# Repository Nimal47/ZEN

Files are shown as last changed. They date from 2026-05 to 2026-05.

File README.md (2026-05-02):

# ZEN — Ambient Desk Intelligent System (ADIS)

> An IoT-based smart desk system that monitors student productivity through real-time presence detection and device usage tracking.

---

## What It Does

ZEN sits on your desk and silently tracks how focused you actually are:

- **Presence Detection** — A PIR sensor continuously checks if you're at your desk
- **Phone Distraction Tracking** — An RFID tag on your phone logs every time you pick it up, giving you a distraction count and duration
- **On-Desk Interface** — A TFT display with button navigation gives you a timer, stopwatch, and reminder alerts without needing your phone
- **Productivity Analytics** — All sensor data is logged to Firebase and visualized in a companion app (in progress)

---

## Hardware Components

| Component | Model |
|---|---|
| Microcontroller | ESP32 DOIT DevKit V1 |
| Display | TFT ST7735 / ST7789 |
| OLED | SSD1306 128×64 |
| RFID Module | MFRC522 |
| Presence Sensor | PIR Motion Sensor |
| Power | LiPo Battery |
| Buttons | 2× Tactile Push Buttons |

---

## Pin Configuration

### TFT Display (SPI)
| TFT Pin | ESP32 GPIO |
|---|---|
| CS | 5 |
| DC | 2 |
| RST | 4 |
| SCK | 18 (VSPI default) |
| MOSI | 23 (VSPI default) |

### RFID — MFRC522 (SPI, shared bus)
| RFID Pin | ESP32 GPIO |
|---|---|
| CS (SDA) | 21 |
| RST | 22 |
| SCK | 18 |
| MOSI | 23 |
| MISO | 19 |

### OLED — SSD1306 (I2C)
| OLED Pin | ESP32 GPIO |
|---|---|
| SDA | 25 |
| SCL | 26 |

### Other
| Component | ESP32 GPIO |
|---|---|
| PIR Sensor OUT | 27 |
| Button — Mode | 32 |
| Button — Timer | 33 |
| PIR VCC | VIN |
| Battery + | VIN |

---

## Project Structure

```
ZEN/
├── src/                  # Main firmware source code
├── include/              # Header files
├── lib/                  # Local libraries
├── test/                 # PlatformIO unit tests (simulated/virtual)
├── hardware_tests/       # Real-world hardware validation scripts
├── 3D_MODEL/             # 3D printable enclosure files
├── platformio.ini        # PlatformIO build config
└── secret.example.h      # Template for WiFi & Firebase credentials
```

> **`test/` vs `hardware_tests/`** — `test/` is for PlatformIO's native unit testing framework (edge case simulation). `hardware_tests/` contains scripts used to verify real hardware behavior during development.

---

## Getting Started

### 1. Prerequisites

- [PlatformIO](https://platformio.org/) (VS Code extension or CLI)
- ESP32 board drivers installed
- A Firebase project with Realtime Database enabled

### 2. Clone the Repo

```bash
git clone https://github.com/Nimal47/ZEN.git
cd ZEN
```

### 3. Set Up Credentials

Copy the example secrets file and fill in your own values:

```bash
cp secret.example.h include/secret.h
```

Then open `include/secret.h` and fill in your WiFi and Firebase details. **Never commit `secret.h`** — it's already in `.gitignore`.

### 4. Flash to ESP32

```bash
pio run --target upload
```

Monitor serial output:

```bash
pio device monitor
```

---

## Firebase Setup

1. Go to [Firebase Console](https://console.firebase.google.com/) and create a new project
2. Enable **Realtime Database** (start in test mode for development)
3. Go to **Project Settings → Service Accounts** and note your database URL
4. Go to **Project Settings → General** and copy your **Web API Key**
5. Fill these into `include/secret.h`

---

## Dependencies (auto-installed by PlatformIO)

| Library | Purpose |
|---|---|
| Adafruit GFX Library | Graphics primitives |
| Adafruit ST7735/ST7789 | TFT display driver |
| Adafruit SSD1306 | OLED display driver |
| MFRC522 | RFID module |
| ArduinoJson | JSON serialization |
| Firebase Arduino Client Library | Firebase Realtime Database |

---

## Companion App

A mobile companion app that visualizes your productivity data from Firebase is currently in development. It will show daily distraction counts, focus session durations, and trend graphs.

---

## License

This project is licensed under the [MIT License](LICENSE).

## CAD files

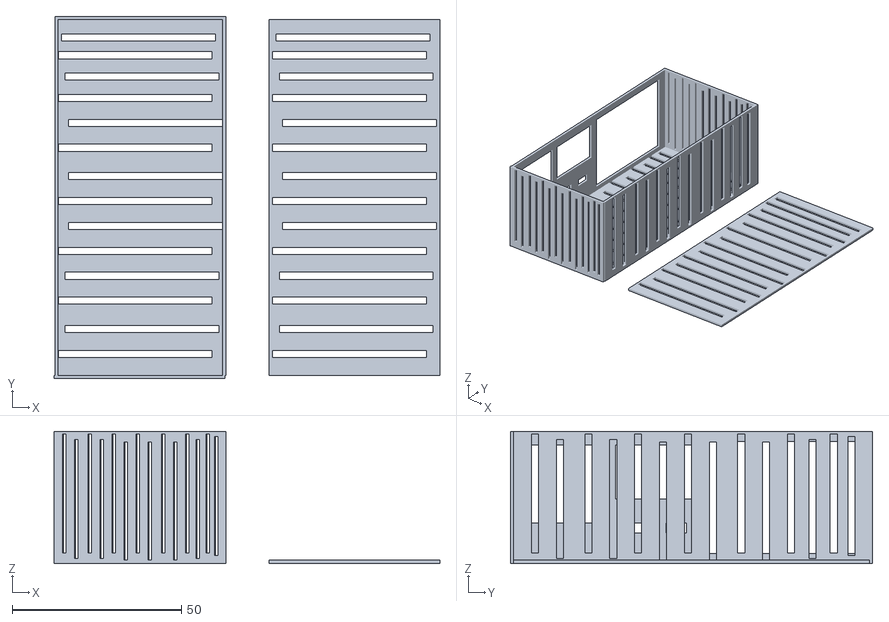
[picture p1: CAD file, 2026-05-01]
3D_MODEL/Final_model.stl
114.0 x 107.0 x 39.0

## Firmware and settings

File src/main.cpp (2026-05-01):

#include <Arduino.h>
#include <SPI.h>
#include <Adafruit_GFX.h>
#include <Adafruit_ST7735.h>
#include <MFRC522.h>
#include <WiFi.h>
#include "time.h"
#include <Adafruit_SSD1306.h>
#include <Firebase_ESP_Client.h>
#include <ArduinoJson.h>
#include "addons/RTDBHelper.h"
#include "/Users/nimal/Documents/PROJEC/MP3/django.h" //path to Image Header File in C array Format
#include "/Users/nimal/Documents/PROJEC/ADIS/src/secret.h" //path to your Credential folder 

// --- WI-FI CREDENTIALS ---
const char* ssid     = WIFI_SSID;
const char* password = WIFI_PASSWORD;

// --- SYSTEM TIMING CONSTANTS ---
#define SCREEN_AWAKE_MS       10000  
#define SCREEN_SLEEP_WARN_MS  12000  
#define TIMER_AUTOSTART_SEC   5      
#define TIME_UP_DISPLAY_MS    5000   
#define RFID_TIMEOUT_MS       2000   
#define FOCUS_POPUP_MS        3000   
#define SYNC_HOUR             23
#define SYNC_MINUTE           30

// --- PIN DEFINITIONS ---
#define TFT_CS      5
#define TFT_DC      2
#define TFT_RST     4
#define PIR_PIN     27
#define RFID_CS     21
#define RFID_RST    22
#define BTN_MODE    32 
#define BTN_TIMER   33 

#define OLED_SDA    25
#define OLED_SCL    26
#define SCREEN_WIDTH 128
#define SCREEN_HEIGHT 64

// --- HARDWARE OBJECTS ---
Adafruit_ST7735 tft = Adafruit_ST7735(TFT_CS, TFT_DC, TFT_RST);
MFRC522 mfrc522(RFID_CS, RFID_RST);
Adafruit_SSD1306 oled(SCREEN_WIDTH, SCREEN_HEIGHT, &Wire, -1);
FirebaseData fbdo;
FirebaseAuth auth;
FirebaseConfig config;

// --- SHARED RTOS VARIABLES & LOCKS ---
volatile TickType_t lastMotionTick = 0; 
SemaphoreHandle_t spiMutex;

// System Modes (NOW INCLUDES STOPWATCH)

enum SystemMode { MODE_DEFAULT, MODE_TIMER, MODE_STOPWATCH, MODE_REMINDER };
volatile SystemMode currentMode = MODE_DEFAULT;

// --- MANUAL TIMER VARIABLES ---
volatile int timerMinutes = 1;  
volatile TickType_t lastTimerInteractionTick = 0; 
volatile bool isTimerRunning = false;             
volatile TickType_t timerStartTick = 0;           
volatile TickType_t timeUpStartTick = 0; 

// Focus Session Data
struct FocusSession {
    String startTime;
    String endTime;
    int durationSec;
};

std::vector<FocusSession> dailyLog;
struct Reminder {
    String time;
    String text;
};
std::vector<Reminder> reminderList; // Holds all our downloaded reminders!

// --- NEW: STOPWATCH VARIABLES ---
volatile bool isStopwatchRunning = false;
volatile unsigned long accumulatedStopwatchSeconds = 0;
volatile TickType_t stopwatchStartTick = 0;

// --- PHONE JAIL NOTIFICATION VARIABLES ---
volatile bool isPhoneInJail = false;
volatile TickType_t jailStartTime = 0;
volatile bool showJailStartMessage = false;
volatile TickType_t jailStartMessageTick = 0;
volatile bool showJailSummary = false;
volatile TickType_t summaryStartTick = 0;
volatile int lastFocusSeconds = 0;

// Display States
enum DisplayState {
  STATE_AWAKE_DEFAULT,
  STATE_AWAKE_TIMER,
  STATE_AWAKE_STOPWATCH,   // NEW STATE!
  STATE_AWAKE_REMINDER,
  STATE_AWAKE_FOCUS_START, 
  STATE_AWAKE_SUMMARY,     
  STATE_SLEEPING_TEXT,
  STATE_ASLEEP
};

// =======================================================
// TASK 1: NETWORK MANAGER
// =======================================================
void networkTask(void *parameter) {
    Serial.println("📡 [NETWORK] Task started. Attempting Wi-Fi connection...");
    WiFi.begin(ssid, password);
    while (WiFi.status() != WL_CONNECTED) {
        vTaskDelay(pdMS_TO_TICKS(500));
        Serial.print(".");
    }
    Serial.println("\n✅ [NETWORK] Wi-Fi Connected!");
    Serial.print("🌐 [NETWORK] IP Address Assigned: ");
    Serial.println(WiFi.localIP());
    
    Serial.println("🕒 [NETWORK] Requesting NTP Time Sync...");
    configTime(19800, 0, "time.google.com");
    struct tm timeinfo;
    if (getLocalTime(&timeinfo)) {
        Serial.println("✅ [NETWORK] Time Synced Successfully!");
    } else {
        Serial.println("❌ [NETWORK] WARNING: Failed to obtain local time!");
    }
    
    Serial.println("🔥 [FIREBASE] Initializing connection to database...");
    config.database_url = FIREBASE_HOST;
    config.signer.tokens.legacy_token = FIREBASE_AUTH;
    Firebase.begin(&config, &auth);
    Firebase.reconnectWiFi(true);
    Serial.println("✅ [FIREBASE] Client Initialized.");

    bool hasSyncedToday = false;
    int lastPullMinute = -1; // Prevents fetching data multiple times in the same minute

    for (;;) {
        if (getLocalTime(&timeinfo)) {
            
            // 1. DAILY DATA PUSH (11:30 PM)
            if (timeinfo.tm_hour == SYNC_HOUR && timeinfo.tm_min == SYNC_MINUTE && !hasSyncedToday) {
                Serial.printf("\n☁️ [FIREBASE] --- INITIATING DAILY SYNC --- \n");
                Serial.printf("📊 [FIREBASE] Sessions currently in local buffer: %d\n", dailyLog.size());
                
                if (dailyLog.size() > 0) {
                    for (const auto& session : dailyLog) {
                        FirebaseJson json;
                        json.add("start", session.startTime);
                        json.add("end", session.endTime);
                        json.add("duration", session.durationSec);
                        
                        // Convert JSON to string just so we can print and verify it
                        String jsonStr;
                        json.toString(jsonStr, false);
                        Serial.printf("📤 [FIREBASE] Pushing Payload: %s\n", jsonStr.c_str());

                        // Attempt the actual push
                        if (Firebase.RTDB.pushJSON(&fbdo, "/focus_sessions", &json)) {
                            Serial.println("✅ [FIREBASE] Push Success! Saved at path: " + fbdo.dataPath());
                        } else {
                            Serial.println("❌ [FIREBASE] PUSH FAILED! Reason: " + fbdo.errorReason());
                        }
                    }
                    dailyLog.clear(); 
                    Serial.println("🗑️ [LOCAL LOG] Local buffer cleared for the next day.");
                } else {
                    Serial.println("ℹ️ [FIREBASE] No valid focus sessions to push today.");
                }
                Serial.println("☁️ [FIREBASE] --- DAILY SYNC COMPLETE --- \n");
                hasSyncedToday = true;
            }
            
            // Reset the sync flag at midnight
            if (timeinfo.tm_hour == 0) hasSyncedToday = false; 

            // 2. PERIODIC REMINDER PULL (Exactly once every 1 minutes)
            if (timeinfo.tm_min %  1 == 0 && timeinfo.tm_min != lastPullMinute) {
                lastPullMinute = timeinfo.tm_min; 
                
                Serial.println("\n📥 [FIREBASE] Requesting JSON reminders...");
                
                // Fetch the whole JSON object instead of a single string
                if (Firebase.RTDB.getJSON(&fbdo, "/reminders")) {
                    FirebaseJson &json = fbdo.jsonObject();
                    size_t len = json.iteratorBegin();
                    String key, value;
                    int type;
                    
                    reminderList.clear(); // Empty the old list from memory
                    
                    // Loop through the JSON and pull out every time and task
                    for (size_t i = 0; i < len; i++) {
                        json.iteratorGet(i, type, key, value);
                        value.replace("\"", ""); // Clean up JSON quote marks
                        reminderList.push_back({key, value});
                    }
                    json.iteratorEnd();
                    
                    Serial.printf("✅ [FIREBASE] Loaded %d reminders from cloud.\n", reminderList.size());
                } else {
                    Serial.println("❌ [FIREBASE] Failed to fetch reminders! Reason: " + fbdo.errorReason());
                }
            }
        }
        
        // Loop runs once a second to keep exact track of time without spamming
        vTaskDelay(pdMS_TO_TICKS(1000)); 
    }
}

// =======================================================
// TASK 2: PIR WATCHER
// =======================================================
void pirTask(void *parameter) {
  pinMode(PIR_PIN, INPUT);
  for (;;) {
    if (digitalRead(PIR_PIN) == HIGH) {
      lastMotionTick = xTaskGetTickCount(); 
    }
    vTaskDelay(pdMS_TO_TICKS(100)); 
  }
}

// --- UTILITY: GET TIME STRING ---
String getTimestamp() {
    struct tm timeinfo;
    if(!getLocalTime(&timeinfo)) return "00:00:00";
    char timeStr[20];
    strftime(timeStr, sizeof(timeStr), "%H:%M:%S", &timeinfo);
    return String(timeStr);
}

// =======================================================
// TASK 3: BUTTON MANAGER
// =======================================================
void buttonTask(void *parameter) {
  pinMode(BTN_MODE, INPUT_PULLUP);
  pinMode(BTN_TIMER, INPUT_PULLUP);

  int lastModeState = HIGH;
  int lastTimerState = HIGH;

  for (;;) {
    int modeState = digitalRead(BTN_MODE);
    int timerState = digitalRead(BTN_TIMER);

    // --- BUTTON 1: CHANGE MODE ---
    if (modeState == LOW && lastModeState == HIGH) {
      // Now cycles through 4 modes instead of 3
      currentMode = (SystemMode)((currentMode + 1) % 4); 
      lastMotionTick = xTaskGetTickCount(); 
      
      // Reset Timer if entering Timer Mode
      if (currentMode == MODE_TIMER) {
        lastTimerInteractionTick = xTaskGetTickCount();
        isTimerRunning = false; 
      }
      
      // Reset Stopwatch if entering Stopwatch Mode
      if (currentMode == MODE_STOPWATCH) {
        isStopwatchRunning = false;
        accumulatedStopwatchSeconds = 0; 
      }
      
      Serial.printf("🔘 Mode Switched: %d\n", currentMode);
    }
    lastModeState = modeState;

    // --- BUTTON 2: ACTION BUTTON ---
    if (timerState == LOW && lastTimerState == HIGH) {
      lastMotionTick = xTaskGetTickCount(); 
      
      // Action for Timer Mode
      if (currentMode == MODE_TIMER) {
        if (timerMinutes == 1) timerMinutes = 5;
        else if (timerMinutes == 5) timerMinutes = 15;
        else if (timerMinutes == 15) timerMinutes = 30;
        else if (timerMinutes == 30) timerMinutes = 60;
        else timerMinutes = 1; 
        
        lastTimerInteractionTick = xTaskGetTickCount(); 
        isTimerRunning = false;                         
        Serial.printf("⏱️ Timer Set To: %d min\n", timerMinutes);
      }
      
      // Action for Stopwatch Mode (Play/Pause Toggle)
      else if (currentMode == MODE_STOPWATCH) {
        if (isStopwatchRunning) {
          // PAUSE IT
          isStopwatchRunning = false;
          // Save the time we accrued so far
          accumulatedStopwatchSeconds += (xTaskGetTickCount() - stopwatchStartTick) / 1000;
          Serial.println("⏸️ Stopwatch Paused");
        } else {
          // START/RESUME IT
          isStopwatchRunning = true;
          stopwatchStartTick = xTaskGetTickCount();
          Serial.println("▶️ Stopwatch Started");
        }
      }
    }
    lastTimerState = timerState;
    vTaskDelay(pdMS_TO_TICKS(50)); 
  }
}

// =======================================================
// TASK 4: PHONE JAIL RFID
// =======================================================
void rfidTask(void *parameter) {
  // Give the main setup a moment to initialize the SPI bus
  vTaskDelay(pdMS_TO_TICKS(1000));
  
  if (xSemaphoreTake(spiMutex, portMAX_DELAY)) {
    mfrc522.PCD_Init();
    xSemaphoreGive(spiMutex);
  }
  
  TickType_t lastCardSeenTime = 0;
  String sessionStartStr; // Temporarily holds the start time for Firebase

  for (;;) {
    TickType_t currentTick = xTaskGetTickCount();
    MFRC522::StatusCode status;
    byte bufferATQA[2];
    byte bufferSize = sizeof(bufferATQA);

    // --- CRITICAL SECTION: LOCK SPI BUS TO READ RFID ---
    if (xSemaphoreTake(spiMutex, portMAX_DELAY)) {
      status = mfrc522.PICC_WakeupA(bufferATQA, &bufferSize);
      if (status == MFRC522::STATUS_OK && mfrc522.PICC_ReadCardSerial()) {
        mfrc522.PICC_HaltA(); 
      }
      xSemaphoreGive(spiMutex);
    }

    if (status == MFRC522::STATUS_OK) {
      lastCardSeenTime = currentTick;
      
      if (!isPhoneInJail) {
        // --- PHONE JUST ENTERED JAIL ---
        isPhoneInJail = true;
        jailStartTime = currentTick;
        sessionStartStr = getTimestamp(); // Capture the exact Start Time for Firebase
        
        showJailStartMessage = true;          // Trigger the 3-second Start Popup
        jailStartMessageTick = currentTick;   
        showJailSummary = false;              // Cancel any old summaries
        
        lastMotionTick = currentTick;         // Wake up screen instantly
        Serial.println("\n🔒 Phone Locked in Jail! Focus time started.");
      }
    } else {
      // Timeout Check: Phone lifted for more than 2 seconds (RFID_TIMEOUT_MS)
      if (isPhoneInJail && (currentTick - lastCardSeenTime > pdMS_TO_TICKS(RFID_TIMEOUT_MS))) {
        
        // --- PHONE JUST LEFT JAIL ---
        isPhoneInJail = false;
        
        // Calculate duration (subtracting the 2 second timeout buffer)
        int duration = (currentTick - jailStartTime - pdMS_TO_TICKS(RFID_TIMEOUT_MS)) / 1000;
        lastFocusSeconds = duration; // Save for the Display summary
        
        // --- FIREBASE LOGIC: ONLY SAVE IF > 15 MIN (900 seconds) ---
        Serial.printf("\n📱 [RFID] Phone removed. Total focus duration: %d seconds.\n", duration);
        if (duration >= 900) {
            dailyLog.push_back({sessionStartStr, getTimestamp(), duration});
            Serial.println("💾 Session valid (>15m). Saved to local buffer for 11:30 PM sync.");
        } else {
            Serial.println("⚠️ Session too short (<15m), discarded from Firebase log.");
        }
        
        showJailStartMessage = false;         // Cancel start message if picked up instantly
        showJailSummary = true;               // Trigger the 3-second End Popup
        summaryStartTick = currentTick;       
        
        lastMotionTick = currentTick;         // Wake up screen to show summary
        Serial.printf("🔓 Phone Removed! Focused for %d seconds\n", lastFocusSeconds);
      }
    }
    
    // Check for the phone twice a second
    vTaskDelay(pdMS_TO_TICKS(500)); 
  }
}

// =======================================================
// TASK 5: DISPLAY MANAGER
// =======================================================
void displayTask(void *parameter) {
  vTaskDelay(pdMS_TO_TICKS(500));
  
  if (xSemaphoreTake(spiMutex, portMAX_DELAY)) {
    tft.initR(INITR_BLACKTAB);
    tft.setRotation(1);
    tft.fillScreen(ST77XX_BLACK);
    xSemaphoreGive(spiMutex);
  }

  DisplayState currentState = STATE_ASLEEP; 
  int lastDrawnTimerSecond = -1; 
  int lastDrawnStopwatchSecond = -1; // Added for Stopwatch anti-flicker
  int lastSetupCountdown = -1; 

  for (;;) {
    TickType_t currentTick = xTaskGetTickCount();
    TickType_t timeSinceMotion = currentTick - lastMotionTick;

    // RULE 1: AWAKE
    if (timeSinceMotion < pdMS_TO_TICKS(SCREEN_AWAKE_MS)) {
      
      // --- NOTIFICATION OVERRIDE A: FOCUS STARTED ---
      if (showJailStartMessage) {
        lastMotionTick = currentTick; 
        if (currentState != STATE_AWAKE_FOCUS_START) {
          if (xSemaphoreTake(spiMutex, portMAX_DELAY)) {
            tft.fillScreen(ST77XX_BLACK);
            tft.setCursor(5, 50);
            tft.setTextColor(ST77XX_MAGENTA);
            tft.setTextSize(2);
            tft.print("FOCUS MODE");
            tft.setCursor(20, 80);
            tft.setTextColor(ST77XX_WHITE);
            tft.setTextSize(1);
            tft.print("Tracking started...");
            xSemaphoreGive(spiMutex);
          }
          currentState = STATE_AWAKE_FOCUS_START;
        }
        if (currentTick - jailStartMessageTick > pdMS_TO_TICKS(FOCUS_POPUP_MS)) {
          showJailStartMessage = false;
          currentState = STATE_ASLEEP; 
        }
      }
      
      // --- NOTIFICATION OVERRIDE B: FOCUS SUMMARY ---
      else if (showJailSummary) {
        lastMotionTick = currentTick; 
        if (currentState != STATE_AWAKE_SUMMARY) {
          if (xSemaphoreTake(spiMutex, portMAX_DELAY)) {
            tft.fillScreen(ST77XX_BLACK);
            tft.setCursor(5, 30);
            tft.setTextColor(ST77XX_CYAN);
            tft.setTextSize(2);
            tft.print("FOCUS OVER");
            tft.setCursor(25, 70);
            tft.setTextColor(ST77XX_WHITE);
            tft.setTextSize(3);
            tft.printf("%02d:%02d", lastFocusSeconds / 60, lastFocusSeconds % 60);
            xSemaphoreGive(spiMutex);
          }
          currentState = STATE_AWAKE_SUMMARY;
        }
        if (currentTick - summaryStartTick > pdMS_TO_TICKS(FOCUS_POPUP_MS)) {
          showJailSummary = false;
          currentState = STATE_ASLEEP; 
        }
      }

      // --- STANDARD MODES ---
      else {
        
        // --- MODE 0: CYBERPUNK IMAGE ---
        if (currentMode == MODE_DEFAULT) {
          if (currentState != STATE_AWAKE_DEFAULT) {
            if (xSemaphoreTake(spiMutex, portMAX_DELAY)) {
              tft.fillScreen(ST77XX_BLACK);
              tft.drawRGBBitmap(15, 0, django, 128, 160);
              xSemaphoreGive(spiMutex);
            }
            currentState = STATE_AWAKE_DEFAULT;
          }
        }
        
        // --- MODE 1: COUNTDOWN TIMER ---
        else if (currentMode == MODE_TIMER) {
          bool justWokeUp = (currentState != STATE_AWAKE_TIMER);
          currentState = STATE_AWAKE_TIMER; 
          
          if (!isTimerRunning) {
            long waitTimeRemaining = TIMER_AUTOSTART_SEC - ((currentTick - lastTimerInteractionTick) / 1000);
            if (waitTimeRemaining <= 0) {
              isTimerRunning = true;
              timerStartTick = currentTick;
              lastDrawnTimerSecond = -1; 
              if (xSemaphoreTake(spiMutex, portMAX_DELAY)) {
                 tft.fillScreen(ST77XX_BLACK);
                 xSemaphoreGive(spiMutex);
              }
            } 
            else if (waitTimeRemaining != lastSetupCountdown || justWokeUp) {
              if (xSemaphoreTake(spiMutex, portMAX_DELAY)) {
                tft.fillScreen(ST77XX_BLACK);
                tft.setCursor(10, 30);
                tft.setTextColor(ST77XX_GREEN);
                tft.setTextSize(2);
                tft.print("TIMER SETUP");
                tft.setCursor(30, 60);
                tft.setTextColor(ST77XX_WHITE);
                tft.setTextSize(3);
                tft.printf("%02d M", timerMinutes);
                tft.setCursor(15, 100);
                tft.setTextColor(ST77XX_YELLOW);
                tft.setTextSize(1);
                tft.printf("Auto-start in %d...", waitTimeRemaining);
                xSemaphoreGive(spiMutex);
              }
              lastSetupCountdown = waitTimeRemaining;
            }
          }
          else {
            long elapsedSeconds = (currentTick - timerStartTick) / 1000;
            long totalSeconds = timerMinutes * 60;
            long remainingSeconds = totalSeconds - elapsedSeconds;
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
void loop() {}

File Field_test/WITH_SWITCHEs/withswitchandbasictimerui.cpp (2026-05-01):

#include <Arduino.h>
#include <SPI.h>
#include <Adafruit_GFX.h>
#include <Adafruit_ST7735.h>
#include <MFRC522.h>
#include <WiFi.h>
#include "time.h"

#include "/Users/nimal/Documents/PROJEC/MP3/goodman.h" //path to Image Header File in C array Format
#include "/Users/nimal/Documents/PROJEC/ADIS/src/secret.h" //path to your Credential folder 

// --- WI-FI CREDENTIALS ---
const char* ssid     = WIFI_SSID;
const char* password = WIFI_PASSWORD;
// --- PIN DEFINITIONS ---
#define TFT_CS      5
#define TFT_DC      2
#define TFT_RST     4
#define PIR_PIN     27
#define RFID_CS     21
#define RFID_RST    22
#define BTN_MODE    32 // New Button 1
#define BTN_TIMER   33 // New Button 2

// --- HARDWARE OBJECTS ---
Adafruit_ST7735 tft = Adafruit_ST7735(TFT_CS, TFT_DC, TFT_RST);
MFRC522 mfrc522(RFID_CS, RFID_RST);

// --- SHARED RTOS VARIABLES & LOCKS ---
volatile TickType_t lastMotionTick = 0; 
SemaphoreHandle_t spiMutex;

// System Modes
enum SystemMode {
  MODE_DEFAULT,
  MODE_TIMER,
  MODE_REMINDER
};
volatile SystemMode currentMode = MODE_DEFAULT;
volatile int timerMinutes = 5; // Tracks the 5, 15, 30, 60 cycle

// Display States to prevent flickering
enum DisplayState {
  STATE_AWAKE_DEFAULT,
  STATE_AWAKE_TIMER,
  STATE_AWAKE_REMINDER,
  STATE_SLEEPING_TEXT,
  STATE_ASLEEP
};

// =======================================================
// TASK 1: NETWORK MANAGER
// =======================================================
void networkTask(void *parameter) {
  Serial.print("Connecting to Wi-Fi");
  WiFi.begin(ssid, password);
  while (WiFi.status() != WL_CONNECTED) {
    vTaskDelay(pdMS_TO_TICKS(500));
    Serial.print(".");
  }
  Serial.println("\nWi-Fi Connected!");
  configTime(19800, 0, "time.google.com", "pool.ntp.org");
  vTaskDelete(NULL); 
}

// =======================================================
// TASK 2: PIR WATCHER
// =======================================================
void pirTask(void *parameter) {
  pinMode(PIR_PIN, INPUT);
  for (;;) {
    if (digitalRead(PIR_PIN) == HIGH) {
      lastMotionTick = xTaskGetTickCount(); 
    }
    vTaskDelay(pdMS_TO_TICKS(100)); 
  }
}

// =======================================================
// TASK 3: BUTTON MANAGER (NEW)
// =======================================================
void buttonTask(void *parameter) {
  pinMode(BTN_MODE, INPUT_PULLUP);
  pinMode(BTN_TIMER, INPUT_PULLUP);

  int lastModeState = HIGH;
  int lastTimerState = HIGH;

  for (;;) {
    int modeState = digitalRead(BTN_MODE);
    int timerState = digitalRead(BTN_TIMER);

    // --- BUTTON 1: CHANGE MODE ---
    if (modeState == LOW && lastModeState == HIGH) {
      currentMode = (SystemMode)((currentMode + 1) % 3); // Cycles 0 -> 1 -> 2 -> 0
      lastMotionTick = xTaskGetTickCount(); // Wake up the screen to show the new mode
      Serial.printf("🔘 Mode Switched: %d\n", currentMode);
    }
    lastModeState = modeState;

    // --- BUTTON 2: CHANGE TIMER ---
    if (timerState == LOW && lastTimerState == HIGH) {
      // Only do something if we are actually in Timer Mode
      if (currentMode == MODE_TIMER) {
        if (timerMinutes == 5) timerMinutes = 15;
        else if (timerMinutes == 15) timerMinutes = 30;
        else if (timerMinutes == 30) timerMinutes = 60;
        else timerMinutes = 5; // Loop back to 5
        
        lastMotionTick = xTaskGetTickCount(); // Wake up the screen to show the new time
        Serial.printf("⏱️ Timer Set To: %d min\n", timerMinutes);
      }
    }
    lastTimerState = timerState;

    // 50ms delay acts as a natural hardware debounce so a single press isn't read twice
    vTaskDelay(pdMS_TO_TICKS(50)); 
  }
}

// =======================================================
// TASK 4: PHONE JAIL RFID
// =======================================================
void rfidTask(void *parameter) {
  vTaskDelay(pdMS_TO_TICKS(1000));
  
  if (xSemaphoreTake(spiMutex, portMAX_DELAY)) {
    mfrc522.PCD_Init();
    xSemaphoreGive(spiMutex);
  }
  
  bool isPhoneInJail = false;
  TickType_t jailStartTime = 0;
  TickType_t lastCardSeenTime = 0;

  for (;;) {
    TickType_t currentTick = xTaskGetTickCount();
    MFRC522::StatusCode status;
    byte bufferATQA[2];
    byte bufferSize = sizeof(bufferATQA);

    if (xSemaphoreTake(spiMutex, portMAX_DELAY)) {
      status = mfrc522.PICC_WakeupA(bufferATQA, &bufferSize);
      if (status == MFRC522::STATUS_OK && mfrc522.PICC_ReadCardSerial()) {
        mfrc522.PICC_HaltA(); 
      }
      xSemaphoreGive(spiMutex);
    }

    if (status == MFRC522::STATUS_OK) {
      lastCardSeenTime = currentTick;
      if (!isPhoneInJail) {
        isPhoneInJail = true;
        jailStartTime = currentTick;
        Serial.println("\n🔒 Phone Locked in Jail!");
      }
    } else {
      if (isPhoneInJail && (currentTick - lastCardSeenTime > pdMS_TO_TICKS(2000))) {
        isPhoneInJail = false;
        TickType_t totalTicks = currentTick - jailStartTime - pdMS_TO_TICKS(2000);
        int focusSeconds = totalTicks / 1000;
        Serial.printf("🔓 Phone Removed! Focused for %02d:%02d\n", focusSeconds / 60, focusSeconds % 60);
      }
    }
    vTaskDelay(pdMS_TO_TICKS(500)); 
  }
}
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
